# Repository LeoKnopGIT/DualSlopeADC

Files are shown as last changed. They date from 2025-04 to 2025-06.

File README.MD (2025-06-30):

# DualSlopeADC

Ein 12-Bit-Dual-Slope-ADC mit CH32V003 Mikrocontroller und 4-stelligem 7-Segment-Display zur Anzeige der gemessenen Gleichspannung.

Projektübersicht
Projektübersicht

## 🔧 Projektüberblick

Dieses Projekt implementiert einen Dual-Slope-Analog-Digital-Wandler (ADC), wie er z. B. in Digitalmultimetern zum Einsatz kommt. Die Schaltung misst Eingangsspannungen im Bereich von 0–3.3 V und visualisiert das Ergebnis auf einem 7-Segment-Display.

## ⚙️ Hardware

| Komponente | Beschreibung |
|---|---|
| Mikrocontroller  | CH32V003 (RISC-V, 48 MHz) |
| Anzeige | 4-stelliges 7-Segment-Display |
| Betriebsspannung | 3.3 V |
| Auflösung | 12 Bit (theoretisch) |
| Zeitauflösung | ~20 ns (Timer mit 48 MHz) |

Schaltung

## 📐 Funktionsweise

### ⏱ Prinzip: Dual-Slope-Wandlung

1. **Integration (Messphase):**  
   Eingangsspannung wird über ein RC-Glied integriert  
   → Spannungsanstieg proportional zu \( V_{in} - V_{off} \)

2. **Gegenintegration (Referenzphase):**  
   Eine konstante Referenzspannung wird integriert, bis der Ausgang wieder 0 V erreicht.

3. **Zeitmessung:**  
   Die Dauer dieser Rücklaufphase ist proportional zur Eingangsspannung.

Simulation

### Simulation
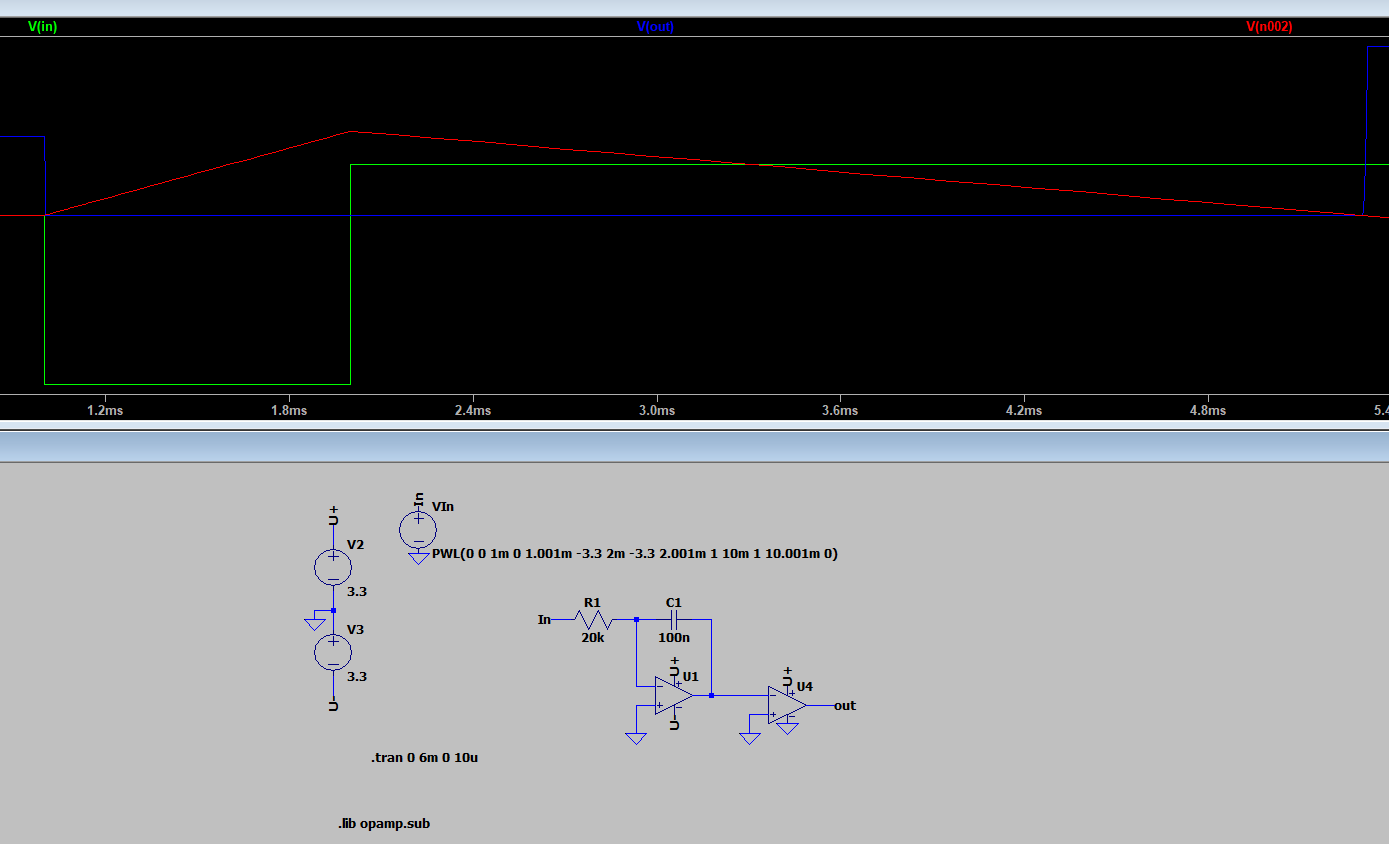
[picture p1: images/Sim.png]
Simulation


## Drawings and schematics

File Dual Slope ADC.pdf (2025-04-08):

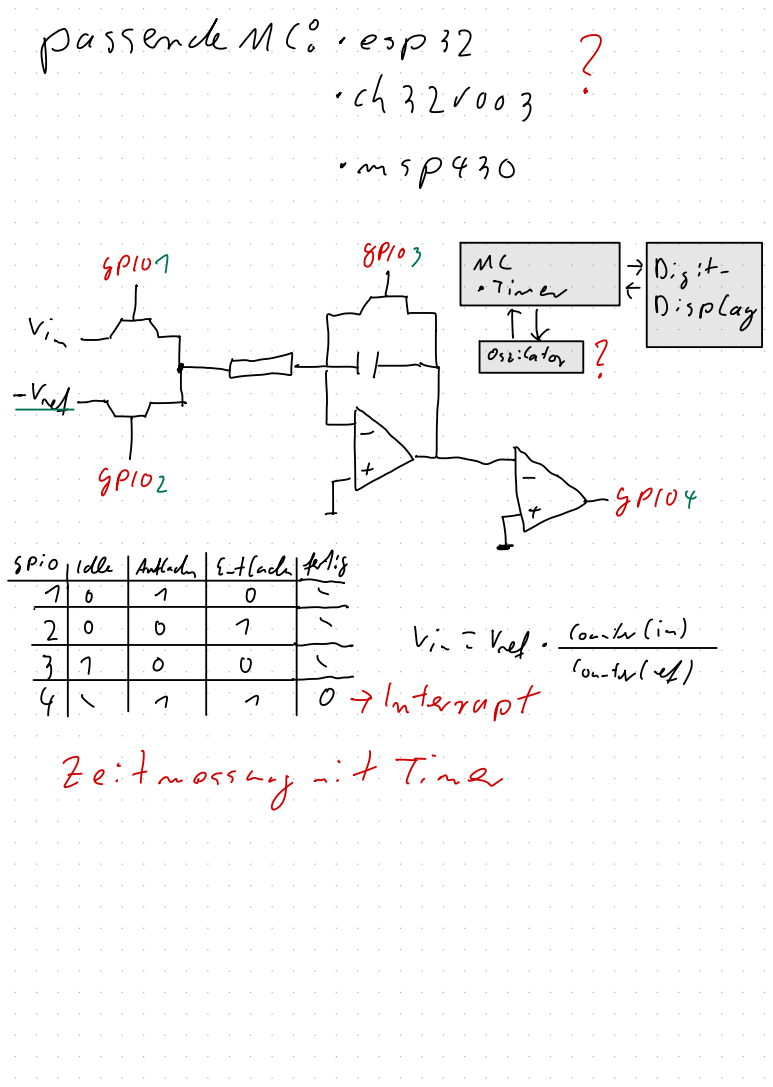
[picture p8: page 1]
passende MC :. esp 32; map430; SPIOL; Digit; · Tim en; Display; ↑ Opt; Spiele; Aufladen; Gutacht; Tor, Interrupt

Zeitmessung mit Timer

in Vete Counter (in)

Con-tr(ef)

·

# EvtVi = UR

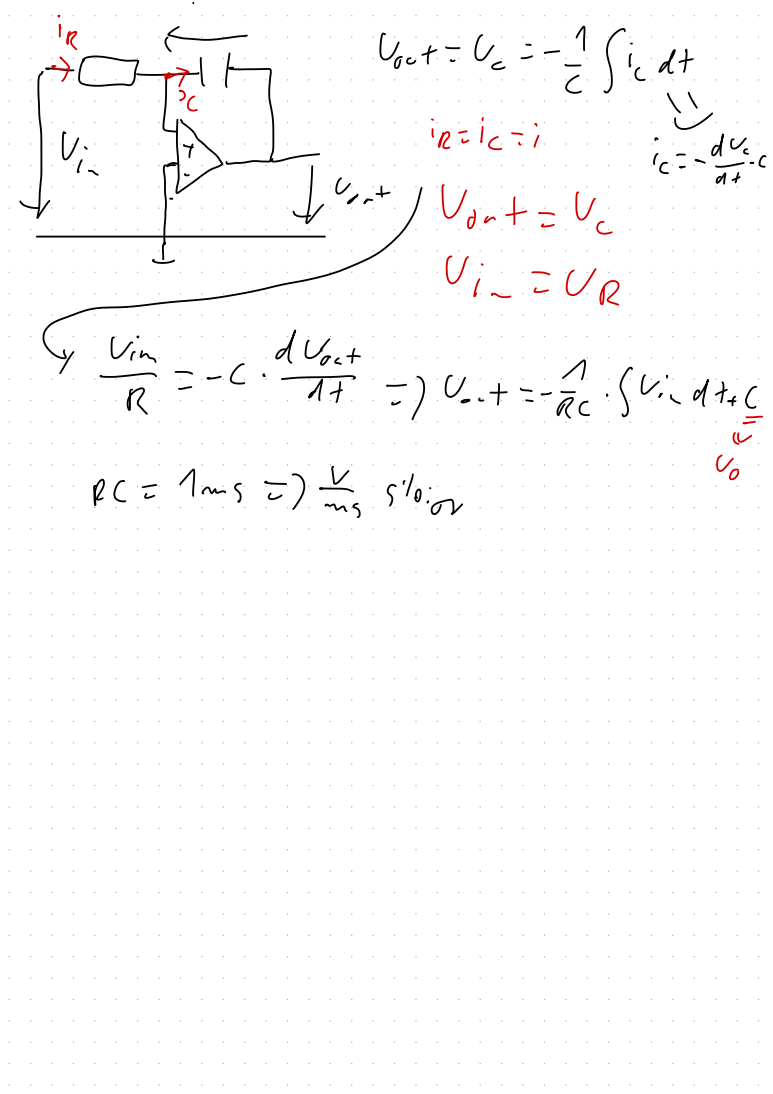
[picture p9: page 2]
Vort = U =; -E Sindt; trat Vort =; Sind; 1ms =) stoid

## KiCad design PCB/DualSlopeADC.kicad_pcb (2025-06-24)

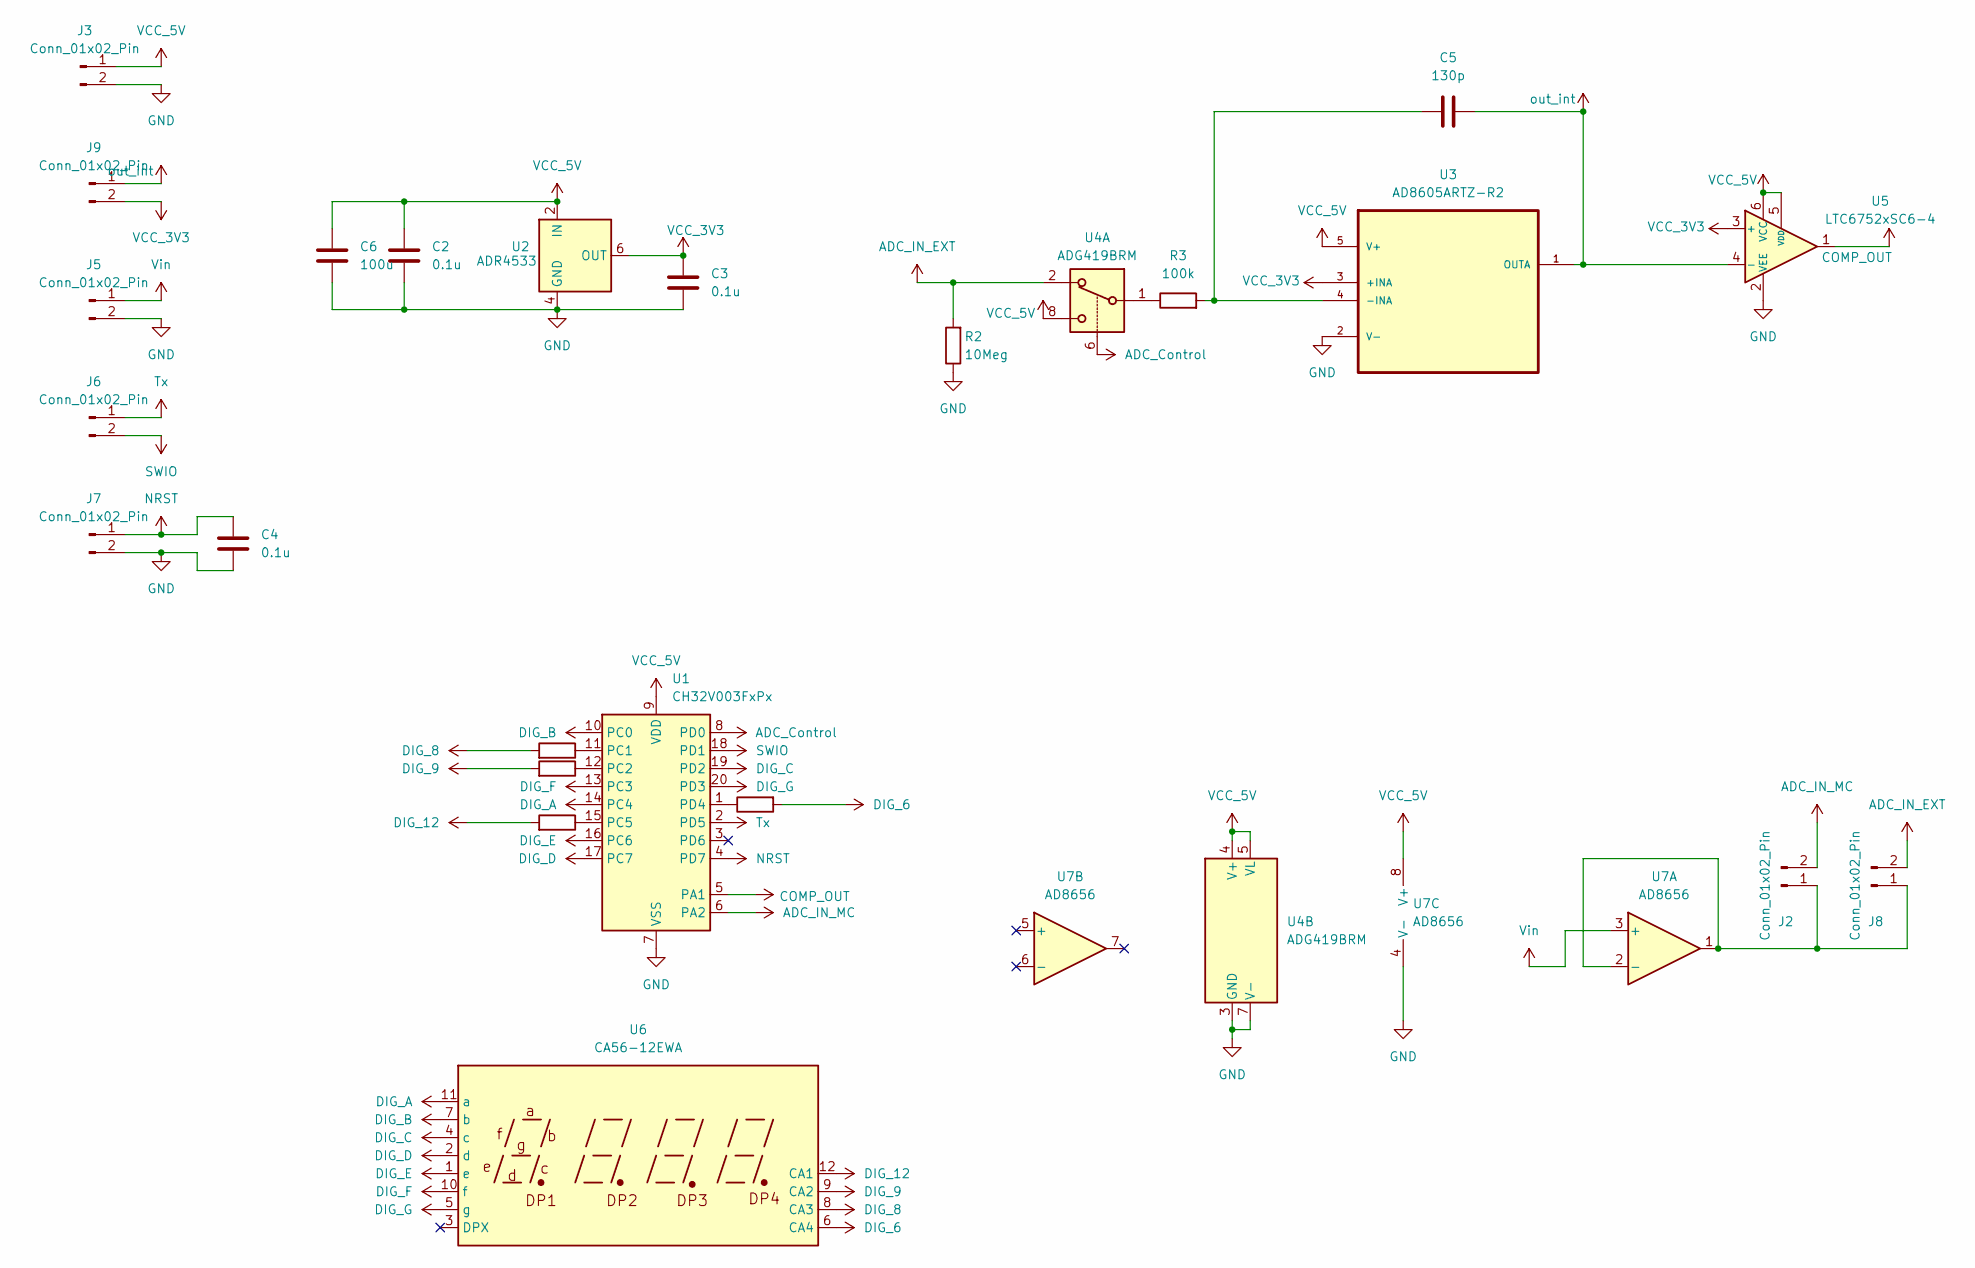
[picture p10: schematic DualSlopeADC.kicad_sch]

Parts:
C2, C3, C4: 0.1u; C_0805_2012Metric
C5: 130p; C_0805_2012Metric
C6: 100u; CP_Radial_D12.5mm_P5.00mm
J2, J3, J5, J6, J7, J8, J9: Conn_01x02_Pin; PinHeader_1x02_P2.54mm_Vertical
R2: 10Meg; R_0603_1608Metric
R3: 100k; R_0603_1608Metric
R4, R5, R6, R7: 330; R_0603_1608Metric
U1: CH32V003FxPx; TSSOP-20_4.4x6.5mm_P0.65mm
U2: ADR4533; SOIC-8_3.9x4.9mm_P1.27mm
U3: AD8605ARTZ-R2; SOT95P290X145-5N; MPN AD8605ARTZ-R2
U4: ADG419BRM; MSOP-8_3x3mm_P0.65mm
U5: LTC6752xSC6-4; SOT-363_SC-70-6
U6: CA56-12EWA; 3461BS_4Digit_7SegDisplay
U7: AD8656; SOIC-8_3.9x4.9mm_P1.27mm

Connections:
ADC_Control: U1.8 (PD0), U4.6
ADC_IN_EXT: J8.2, R2.2, U4.2
ADC_IN_MC: J2.2, U1.6 (PA2)
COMP_OUT: U1.5 (PA1), U5.1
DIG_6: R7.2, U6.6 (CA4)
DIG_8: R6.2, U6.8 (CA3)
DIG_9: R5.2, U6.9 (CA2)
DIG_12: R4.2, U6.12 (CA1)
DIG_A: U1.14 (PC4), U6.11 (a)
DIG_B: U1.10 (PC0), U6.7 (b)
DIG_C: U1.19 (PD2), U6.4 (c)
DIG_D: U1.17 (PC7), U6.2 (d)
DIG_E: U1.16 (PC6), U6.1 (e)
DIG_F: U1.13 (PC3), U6.10 (f)
DIG_G: U1.20 (PD3), U6.5 (g)
GND: C2.2, C3.2, C4.1, C6.2, J3.2, J5.2, J7.2, R2.1, U1.7 (VSS), U2.4 (GND), U3.2 (V-), U4.3 (GND), U4.7 (V-), U5.2 (VEE), U7.4 (V-)
NRST: C4.2, J7.1, U1.4 (PD7)
unnamed: J2.1, J8.1, U7.1, U7.2 (-)
unnamed: R3.1, U4.1
unnamed: R6.1, U1.11 (PC1)
unnamed: R5.1, U1.12 (PC2)
unnamed: R4.1, U1.15 (PC5)
unnamed: R7.1, U1.1 (PD4)
unnamed: C5.1, R3.2, U3.4 (-INA)
SWIO: J6.2, U1.18 (PD1)
Tx: J6.1, U1.2 (PD5)
VCC_3V3: C3.1, J9.2, U2.6 (OUT), U3.3 (+INA), U5.3 (+)
VCC_5V: C2.1, C6.1, J3.1, U1.9 (VDD), U2.2 (IN), U3.5 (V+), U4.4 (V+), U4.5 (VL), U4.8, U5.5 (VDD), U5.6 (VCC), U7.8 (V+)
Vin: J5.1, U7.3 (+)
out_int: C5.2, J9.1, U3.1 (OUTA), U5.4 (-)

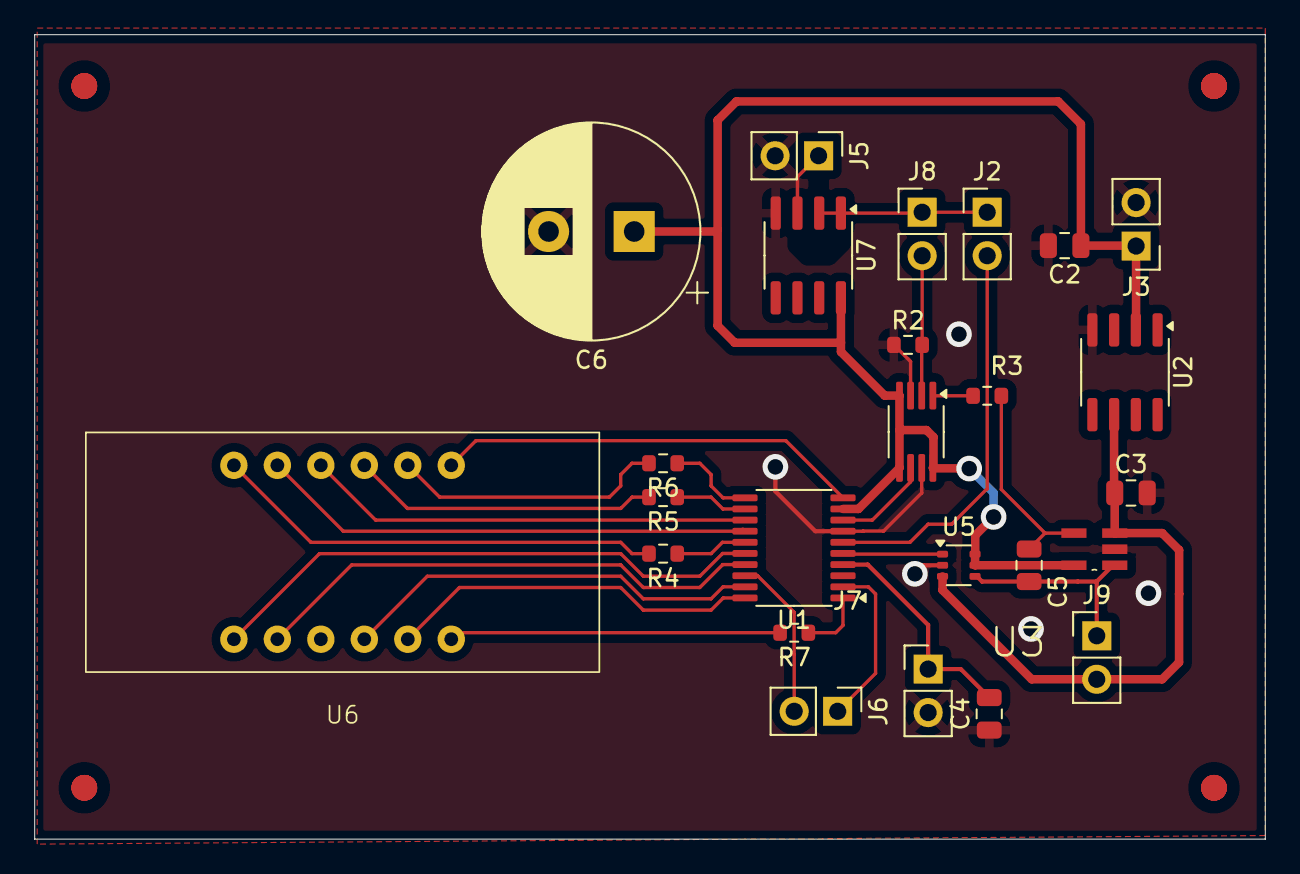
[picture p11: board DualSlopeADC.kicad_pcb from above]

Board: 2 copper layers, 71.9 x 47.0 mm, 25 parts (0 on the bottom side), 30 nets.

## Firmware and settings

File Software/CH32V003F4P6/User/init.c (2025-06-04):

#include "debug.h"

void init_USARTx_CFG(void)
{
    GPIO_InitTypeDef  GPIO_InitStructure = {0};
    USART_InitTypeDef USART_InitStructure = {0};

    RCC_APB2PeriphClockCmd(RCC_APB2Periph_GPIOD | RCC_APB2Periph_USART1, ENABLE);

    /* USART1 TX-->D.5   RX-->D.6 */
    GPIO_InitStructure.GPIO_Pin = GPIO_Pin_5;
    GPIO_InitStructure.GPIO_Speed = GPIO_Speed_30MHz;
    GPIO_InitStructure.GPIO_Mode = GPIO_Mode_AF_PP;
    GPIO_Init(GPIOD, &GPIO_InitStructure);
    GPIO_InitStructure.GPIO_Pin = GPIO_Pin_6;
    GPIO_InitStructure.GPIO_Mode = GPIO_Mode_IN_FLOATING;
    GPIO_Init(GPIOD, &GPIO_InitStructure);

    USART_InitStructure.USART_BaudRate = 115200;
    USART_InitStructure.USART_WordLength = USART_WordLength_8b;
    USART_InitStructure.USART_StopBits = USART_StopBits_1;
    USART_InitStructure.USART_Parity = USART_Parity_No;
    USART_InitStructure.USART_HardwareFlowControl = USART_HardwareFlowControl_None;
    USART_InitStructure.USART_Mode = USART_Mode_Tx | USART_Mode_Rx;

    USART_Init(USART1, &USART_InitStructure);
    USART_Cmd(USART1, ENABLE);
}

void init_GPIO_display(void)
{
    GPIO_InitTypeDef  GPIO_InitStructure = {0};
    RCC_APB2PeriphClockCmd(RCC_APB2Periph_GPIOD | RCC_APB2Periph_GPIOC, ENABLE);

    /* GPIOD init */
    GPIO_InitStructure.GPIO_Pin = GPIO_Pin_2 | GPIO_Pin_3 | GPIO_Pin_4;
    GPIO_InitStructure.GPIO_Speed = GPIO_Speed_50MHz;
    GPIO_InitStructure.GPIO_Mode = GPIO_Mode_Out_PP;
    GPIO_Init(GPIOD, &GPIO_InitStructure);

    /* GPIOC init */
    GPIO_InitStructure.GPIO_Pin = GPIO_Pin_0 | GPIO_Pin_1 | GPIO_Pin_2 | GPIO_Pin_3 | GPIO_Pin_4 | GPIO_Pin_5 | GPIO_Pin_6 | GPIO_Pin_7;
    GPIO_InitStructure.GPIO_Speed = GPIO_Speed_50MHz;
    GPIO_InitStructure.GPIO_Mode = GPIO_Mode_Out_PP;
    GPIO_Init(GPIOC, &GPIO_InitStructure);
}
void init_GPIO_INT(void)
{
    GPIO_InitTypeDef GPIO_InitStructure = {0};
    EXTI_InitTypeDef EXTI_InitStructure = {0};
    NVIC_InitTypeDef NVIC_InitStructure = {0};
    
    RCC_APB2PeriphClockCmd(RCC_APB2Periph_AFIO | RCC_APB2Periph_GPIOA | RCC_APB2Periph_GPIOD, ENABLE );

    GPIO_InitStructure.GPIO_Pin = GPIO_Pin_0;
    GPIO_InitStructure.GPIO_Mode = GPIO_Mode_Out_PP;
    GPIO_InitStructure.GPIO_Speed = GPIO_Speed_50MHz;
    GPIO_Init(GPIOD, &GPIO_InitStructure);

    GPIO_InitStructure.GPIO_Pin = GPIO_Pin_1;
    GPIO_InitStructure.GPIO_Mode = GPIO_Mode_IPD;
    GPIO_InitStructure.GPIO_Speed = GPIO_Speed_50MHz;
    GPIO_Init(GPIOA, &GPIO_InitStructure);

    GPIO_EXTILineConfig(GPIO_PortSourceGPIOA, GPIO_PinSource1);
    EXTI_InitStructure.EXTI_Line = EXTI_Line1;
    EXTI_InitStructure.EXTI_Mode = EXTI_Mode_Interrupt;
    EXTI_InitStructure.EXTI_Trigger = EXTI_Trigger_Rising_Falling;
    EXTI_InitStructure.EXTI_LineCmd = ENABLE;
    EXTI_Init(&EXTI_InitStructure);
    
    NVIC_InitStructure.NVIC_IRQChannel = EXTI7_0_IRQn;
    NVIC_InitStructure.NVIC_IRQChannelPreemptionPriority = 0;
    NVIC_InitStructure.NVIC_IRQChannelSubPriority = 0;
    NVIC_InitStructure.NVIC_IRQChannelCmd = ENABLE;
    NVIC_Init(&NVIC_InitStructure);
}

void init_Timer1(uint16_t prsc, uint16_t arr)
{
    TIM_TimeBaseInitTypeDef TIM_TimeBaseStructure = {0};
    NVIC_InitTypeDef NVIC_InitStructure = {0};
    
    RCC_APB2PeriphClockCmd(RCC_APB2Periph_TIM1, ENABLE);

    TIM_TimeBaseStructure.TIM_Period = arr;
    TIM_TimeBaseStructure.TIM_Prescaler = prsc;
    TIM_TimeBaseStructure.TIM_ClockDivision = TIM_CKD_DIV1;
    TIM_TimeBaseStructure.TIM_CounterMode = TIM_CounterMode_Up;
    TIM_TimeBaseInit(TIM1, &TIM_TimeBaseStructure);

    TIM_ITConfig(TIM1, TIM_IT_Update, ENABLE);

    NVIC_InitStructure.NVIC_IRQChannel = TIM1_UP_IRQn;
    NVIC_InitStructure.NVIC_IRQChannelPreemptionPriority = 0;
    NVIC_InitStructure.NVIC_IRQChannelSubPriority = 1;
    NVIC_InitStructure.NVIC_IRQChannelCmd = ENABLE;
    NVIC_Init(&NVIC_InitStructure);

    TIM_Cmd(TIM1, ENABLE);
}

void init_Timer2(uint16_t prsc, uint16_t arr)
{
    TIM_TimeBaseInitTypeDef TIM_TimeBaseStructure = {0};
    NVIC_InitTypeDef NVIC_InitStructure = {0};
    
    RCC_APB1PeriphClockCmd(RCC_APB1Periph_TIM2, ENABLE);

    TIM_TimeBaseStructure.TIM_Period = arr;
    TIM_TimeBaseStructure.TIM_Prescaler = prsc;
    TIM_TimeBaseStructure.TIM_ClockDivision = TIM_CKD_DIV1;
    TIM_TimeBaseStructure.TIM_CounterMode = TIM_CounterMode_Up;
    TIM_TimeBaseInit(TIM2, &TIM_TimeBaseStructure);

    TIM_ITConfig(TIM2, TIM_IT_Update, ENABLE);

    NVIC_InitStructure.NVIC_IRQChannel = TIM2_IRQn;
    NVIC_InitStructure.NVIC_IRQChannelPreemptionPriority = 0;
    NVIC_InitStructure.NVIC_IRQChannelSubPriority = 1;
    NVIC_InitStructure.NVIC_IRQChannelCmd = ENABLE;
    NVIC_Init(&NVIC_InitStructure);

    TIM_Cmd(TIM2, DISABLE);
}

void initADC(void)
{
     ADC_InitTypeDef ADC_InitStructure = {0};
     GPIO_InitTypeDef GPIO_InitStructure = {0};

     RCC_APB2PeriphClockCmd(RCC_APB2Periph_GPIOA | RCC_APB2Periph_ADC1, ENABLE);
     RCC_ADCCLKConfig(RCC_PCLK2_Div8);

     GPIO_InitStructure.GPIO_Pin = GPIO_Pin_2;
     GPIO_InitStructure.GPIO_Mode = GPIO_Mode_AIN;
     GPIO_Init(GPIOA, &GPIO_InitStructure);

     ADC_DeInit(ADC1);
     ADC_InitStructure.ADC_Mode = ADC_Mode_Independent;
     ADC_InitStructure.ADC_ScanConvMode = DISABLE;
     ADC_InitStructure.ADC_ContinuousConvMode = ENABLE; 
     ADC_InitStructure.ADC_ExternalTrigConv = ADC_ExternalTrigConv_None; 
     ADC_InitStructure.ADC_DataAlign = ADC_DataAlign_Right;
     ADC_InitStructure.ADC_NbrOfChannel = 1;
     ADC_Init(ADC1, &ADC_InitStructure);

     ADC_RegularChannelConfig(ADC1, ADC_Channel_2, 0, ADC_SampleTime_241Cycles);

     ADC_Cmd(ADC1, ENABLE);
     ADC_ResetCalibration(ADC1);
     while(ADC_GetResetCalibrationStatus(ADC1));
     ADC_StartCalibration(ADC1);
     while(ADC_GetCalibrationStatus(ADC1));

     ADC_SoftwareStartConvCmd(ADC1, ENABLE);
}

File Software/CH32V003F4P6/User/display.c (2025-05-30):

#include "debug.h"

const uint8_t segment_map[10][7] = {
    {1,1,1,1,1,1,0}, // 0
    {0,1,1,0,0,0,0}, // 1
    {1,1,0,1,1,0,1}, // 2
    {1,1,1,1,0,0,1}, // 3
    {0,1,1,0,0,1,1}, // 4
    {1,0,1,1,0,1,1}, // 5
    {1,0,1,1,1,1,1}, // 6
    {1,1,1,0,0,0,0}, // 7
    {1,1,1,1,1,1,1}, // 8
    {1,1,1,1,0,1,1}  // 9
};

void display_digit(uint8_t digit)
{
    // Inverses Mapping wegen common-anode (LOW = an)
    if (digit > 9) return;

    // Setze alle Segmentpins aus
    GPIO_WriteBit(GPIOC, GPIO_Pin_4, segment_map[digit][0] ? Bit_RESET : Bit_SET); // a
    GPIO_WriteBit(GPIOC, GPIO_Pin_0, segment_map[digit][1] ? Bit_RESET : Bit_SET); // b
    GPIO_WriteBit(GPIOD, GPIO_Pin_2, segment_map[digit][2] ? Bit_RESET : Bit_SET); // c
    GPIO_WriteBit(GPIOC, GPIO_Pin_7, segment_map[digit][3] ? Bit_RESET : Bit_SET); // d
    GPIO_WriteBit(GPIOC, GPIO_Pin_6, segment_map[digit][4] ? Bit_RESET : Bit_SET); // e
    GPIO_WriteBit(GPIOC, GPIO_Pin_3, segment_map[digit][5] ? Bit_RESET : Bit_SET); // f
    GPIO_WriteBit(GPIOD, GPIO_Pin_3, segment_map[digit][6] ? Bit_RESET : Bit_SET); // g
}

void select_digit(uint8_t digit)
{
    // Clear all digit control lines first
    GPIO_WriteBit(GPIOC, GPIO_Pin_5, Bit_RESET);
    GPIO_WriteBit(GPIOC, GPIO_Pin_2, Bit_RESET);
    GPIO_WriteBit(GPIOC, GPIO_Pin_1, Bit_RESET);
    GPIO_WriteBit(GPIOD, GPIO_Pin_4, Bit_RESET);

    // Enable only the selected digit
    switch (digit) {
        case 0:
            GPIO_WriteBit(GPIOC, GPIO_Pin_5, Bit_SET);
            break;
        case 1:
            GPIO_WriteBit(GPIOC, GPIO_Pin_2, Bit_SET);
            break;
        case 2:
            GPIO_WriteBit(GPIOC, GPIO_Pin_1, Bit_SET);
            break;
        case 3:
            GPIO_WriteBit(GPIOD, GPIO_Pin_4, Bit_SET);
            break;
        default:
            // Invalid index, do nothing
            break;
    }
}
void display_number(uint16_t value)
{
    if (value > 9999) value = 9999;

    // Extract digits (from most significant to least significant)
    uint8_t digits[4] = {
        (value / 1000) % 10,
        (value / 100) % 10,
        (value / 10) % 10,
        value % 10
    };

    for (int i = 0; i < 4; i++) {
        select_digit(i);           // Enable digit i
        display_digit(digits[i]);  // Set segment pattern for that digit
        Delay_Ms(1);               // On-time = 2 ms ¡ú 1/10 multiplex cycle
    }
    GPIO_WriteBit(GPIOC, GPIO_Pin_5, Bit_RESET);
    GPIO_WriteBit(GPIOC, GPIO_Pin_2, Bit_RESET);
    GPIO_WriteBit(GPIOC, GPIO_Pin_1, Bit_RESET);
    GPIO_WriteBit(GPIOD, GPIO_Pin_4, Bit_RESET);
    Delay_Ms(9);
}

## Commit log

2025-04-08 erster Entwurd ADC und Simulation
2025-04-29 out an das Entladen des Kondensators geknüpft
    [DualSlopeADC.kicad_pcb, DualSlopeADC.kicad_sch]
2025-05-10 PCB design anfang
    [DualSlopeADC.kicad_pcb, DualSlopeADC.kicad_sch]
2025-05-13 CH32fun integriert
    [DualSlopeADC.kicad_pcb, DualSlopeADC.kicad_sch]
2025-05-13 Gpio mit Display und Uart funktionieren
2025-05-28 pcb weiter
    [DualSlopeADC.kicad_pcb, DualSlopeADC.kicad_sch]
2025-05-29 schaltpan fertig ohne Spannungsfolger
    [DualSlopeADC.kicad_pcb]
2025-05-30 Software inm Mounriver studio
    [DualSlopeADC.kicad_pcb, DualSlopeADC.kicad_sch]
2025-05-31 platine fertig
    [DualSlopeADC.kicad_pcb, DualSlopeADC.kicad_sch]
2025-06-04 Software ferrig, Timer einstellung auf basis das RC=100us, komplette gehirnschmelze wegen níchtlinearität durch offset sollte aber jetzt passen
    [DualSlopeADC.kicad_pcb, DualSlopeADC.kicad_sch]
2025-06-13 Fehler in pCB behoben durch OP
    [DualSlopeADC.kicad_pcb, DualSlopeADC.kicad_sch]
2025-06-24 visulle sachen
    [DualSlopeADC.kicad_pcb, DualSlopeADC.kicad_sch]
